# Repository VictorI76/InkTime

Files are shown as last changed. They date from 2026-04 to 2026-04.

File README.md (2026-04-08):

# Proiect Hector Watch - nRF52840 Smartwatch

Acest document conține specificațiile tehnice, Bill of Materials (BOM) și detaliile de design pentru proiectul Hector Watch.

---

# 1. Diagramă Bloc
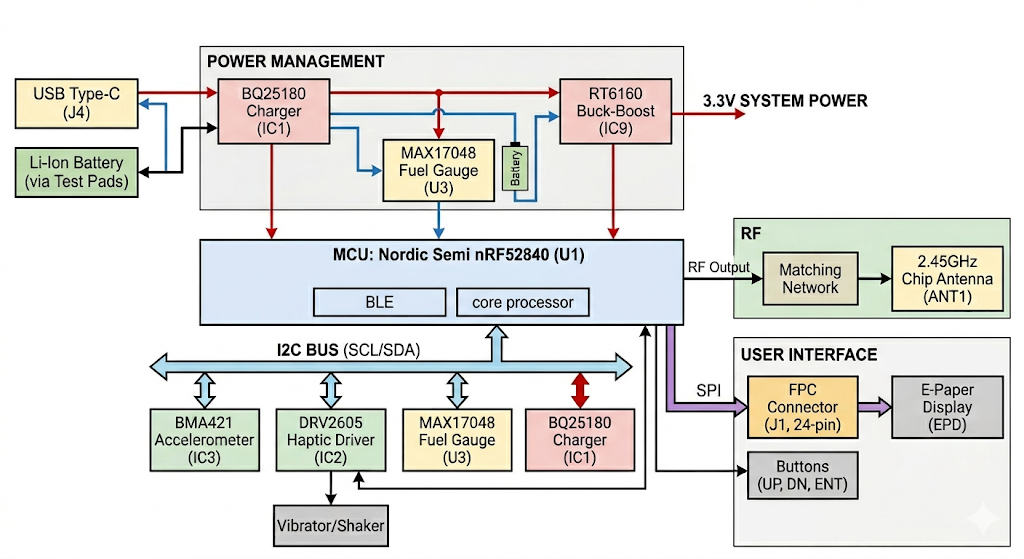
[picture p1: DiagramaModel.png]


---

# 2. Bill Of Materials (BOM)

| Cant. | Referințe | Valoare | Descriere Tehnică | Producător | Cod Piesă (MPN) |
|:---:|:---|:---|:---|:---|:---|
| 1 | U1 | nRF52840 | Microcontroller Bluetooth LE, AQFN-73 | Nordic Semi | nRF52840-QIAA |
| 1 | IC1 | BQ25180 | Charger Li-Ion/Polymer, 8-DSBGA | Texas Instr. | BQ25180YBGR |
| 1 | IC2 | DRV2605 | Driver Haptic LRA/ERM, 9-DSBGA | Texas Instr. | DRV2605YZFR |
| 1 | IC3 | BMA421 | Accelerometru Triaxial 12-bit | Bosch | BMA423 |
| 1 | IC9 | RT6160 | Buck-Boost DC-DC Controller, 15-WL-CSP | Richtek | RT6160AWSC |
| 1 | U3 | MAX17048 | Fuel Gauge (Monitorizare Baterie) | Maxim/ADI | MAX17048G+T10 |
| 1 | ANT1 | 2.45GHz | Antenă Chip Ceramică | Johanson | 2450AT18B100E |
| 1 | J4 | USB-C | Conector USB Type-C 16 pini | Kinghelm | KH-TYPE-C-16P |
| 1 | J1 | FPC 24 | Conector FFC/FPC 0.5mm, 24 pini  | Molex | 503480-2400 |
| 1 | J2 | TC2030 | Interfață programare Tag-Connect | Tag-Connect | TC2030-IDC |
| 3 | SW_DN, SW_ENT, SW_UP | Tactile | Butoane navigare interfață | Panasonic | EVP-AKE31A |
| 1 | L5 | 68uH | Inductor putere ecranat | Wurth | 744043680 |
| 1 | L4 | 0.47uH | Inductor SMD | TDK | FTC252012SR47MBCA |
| 1 | L2 | 10uH | Inductor generic 0402 | - | - |
| 1 | L3 | 15nH | Inductor generic 0201 | - | - |
| 1 | L1 | 3.9nH | Inductor generic 0201  | - | - |
| 1 | X1 | 32MHz | Cristal cuarț (Main Clock)  | - | - |
| 1 | X2 | 32.768kHz | Cristal cuarț (RTC Clock)  | - | - |
| 3 | D2, D4, D5 | MBR0530 | Diodă Schottky 0.5A, 30V, SOD-123 | ON Semi | MBR0530 |
| 1 | D3 | USBLC6-2 | Protecție ESD USB, SOT-23-6 | ST Micro | USBLC6-2SC6Y |
| 1 | Q1 | P-Ch | Tranzistor P-channel MOSFET | - | - |
| 1 | Q3 | N-Ch | Tranzistor N-channel MOSFET 30V, 1.5A | Vishay | Si1308EDL |
| 6 | R2_EP_DR, R5-R9, R_PWR | 10K | Rezistență 0201 Thin Film | - | - |
| 2 | R1_USB, R2_USB | 5K1 | Rezistență 0201 Thin Film  | - | - |
| 2 | R17, R18 | 3K3 | Rezistență 0201 Thin Film  | - | - |
| 3 | R2, R3, R4 | 0 | Rezistență 0201 (Jumper/0 Ohm) | - | - |
| 6 | C5-C19 | 100nF | Condensator decuplare 0201 | - | - |
| 9 | EPD_C1-C12 | 1uF/50V | Condensator 0402 | - | - |
| 5 | C6, C14, C20, C21, C43 | 4.7uF | Condensator 0402  | - | - |
| 3 | C1-EP-DR, C24, C39 | 10uF | Condensator 0402 | - | - |
| 2 | C25, C33 | 22uF | Condensator 0402 | - | - |
| 4 | C23, C27, C34, C42 | 0.1uF | Condensator 0201 | - | - |
| 4 | C1, C2, C17, C18 | 12pF | Condensator 0201 | - | - |
| 14 | TP_3.3V ... TP_VREG | Test Pad | Puncte de testare semnale | - | - |
| 1 | SJ1 | Solder | Jumper de lipit SMD | - | - |

---

# 3. Funcționalității Hardware

## Descrierea Detaliată a Funcționalității Hardware

Proiectul Hector Watch utilizează o arhitectură modulară optimizată pentru eficiență energetică și dimensiuni reduse, având la bază următoarele componente principale:

### 1. Unitatea Centrală de Procesare (MCU)
* **nRF52840 (U1)**: Acesta este un System-on-Chip (SoC) avansat care rulează logica principală a ceasului și gestionează stack-ul Bluetooth Low Energy.
* **Rol**: Controlează comunicația cu toți senzorii prin magistrala **I2C** și interfața digitală pentru display.

### 2. Managementul Puterii (Power Management)
Sistemul de alimentare este proiectat pentru a asigura stabilitate și longevitate bateriei Li-Ion:
* **Încărcător BQ25180 (IC1)**: Gestionează procesul de încărcare a bateriei via USB și include protecții integrate pentru celula de litiu.
* **Regulator Buck-Boost RT6160 (IC9)**: Un convertor DC-DC care stabilizează tensiunea de sistem la 3.3V, indiferent de variațiile tensiunii bateriei.
* **Monitor Baterie MAX17048 (U3)**: Un circuit de tip "Fuel Gauge" care utilizează algoritmul ModelGauge pentru a raporta precis starea de încărcare a bateriei.

## Analiza Consumului de Energie și Autonomie

Pentru a estima durata de viață a bateriei, am analizat principalele stări de funcționare ale componentelor identificate în BOM:

### 1. Consum pe Module (Estimativ)

| Modul / Componentă | Deep Sleep / Standby | Operare Activă (Typical) |
| :--- | :--- | :--- |
| **nRF52840 (U1)** | ~1.5 µA (RTC ON) | ~4.8 mA |
| **BMA421 (IC3)** | ~1 µA (Suspend) | ~14.5 µA (Low Power) |
| **MAX17048 (U3)** | ~3 µA (Hibernate) | ~23 µA (Activ) |
| **RT6160 (IC9)** | ~1 µA (Iq) | Eficiență >85% |
| **Display E-Paper** | **0 µA** (Static) | ~2-8 mA (Refresh doar) |

### 2. Scenariu de Utilizare Tipic
Consumul mediu este calculat pe baza unui ciclu de funcționare (Duty Cycle) în care dispozitivul petrece 99% din timp în mod Sleep:

* **Consum în Sleep (Sistem complet):** ~20 µA (micro-Amperi).
* **Consum în Activitate (Scurte pulsații):** ~5-10 mA (mili-Amperi).
* **Consum Mediu Estimat:** **~55 µA**.

## Calcul Autonomie
Considerând o baterie Li-Ion standard de **200 mAh**:

$$Autonomie (ore) = \frac{Capacitate (mAh)}{Consum Mediu (mA)}$$

$$Autonomie = \frac{200 mAh}{0.055 mA} \approx 3636 \text{ ore}$$

**Rezultat:** Dispozitivul poate funcționa teoretic aproximativ **5 luni** cu o singură încărcare în regim de standby/notificări ocazionale. Utilizarea intensă a motorului haptic (DRV2605) sau refresh-ul frecvent al ecranului va reduce această perioadă la aproximativ **2-4 săptămâni**.

### 3. Senzori și Feedback Haptic
* **Accelerometru BMA421/BMA423 (IC3)**: Senzor de mișcare triaxial cu consum ultra-redus, utilizat pentru pedometru și detecția gesturilor de ridicare a mâinii.
* **Driver Haptic DRV2605 (IC2)**: Controller specializat pentru motoare de vibrație (ERM/LRA) ce oferă o bibliotecă internă de efecte tactile complexe.

### 4. Interfețe și Comunicație
* **Antenă Chip 2.45GHz (ANT1)**: Componentă ceramică acordată pentru frecvența Bluetooth, esențială pentru conexiunea wireless.
* **Conector FPC J1 (24 pini)**: Interfață de 0.5mm utilizată pentru conectarea panoului de afișaj E-Paper.
* **Port USB Type-C (J4)**: Punctul principal de alimentare și încărcare a dispozitivului.
* **Butoane (SW_UP, SW_DN, SW_ENT)**: Trei switch-uri tactice pentru navigarea utilizatorului în meniurile ceasului.

### 5. Protecție și Componente Pasive
* **Protecție ESD USBLC6-2SC6Y (D3)**: Protejează pinii de date USB împotriva descărcărilor electrostatice.
* **Diodă Schottky MBR0530 (D2, D4, D5)**: Componente utilizate pentru redresare și protecția căilor de alimentare.
* **Filtrare locală**: Sistemul utilizează o rețea densă de condensatoare de decuplare (majoritatea în capsulă 0201) pentru a reduce zgomotul electric pe liniile de alimentare.
---

# 4. Alocare Pini nRF52840

## 1. Alimentare și stabilizare

### Pini implicați

* VDD, VDDH
* DEC1, DEC3, DEC4, DEC5, DEC6
* DCC, DCCHP
* VSS (GND)

### Conectare

* VDD este conectat la 3.3V
* VDDH este conectat la sursa principală (baterie sau regulator)
* Pinii DEC sunt conectați la condensatori (100nF, 1µF, 4.7µF) către masă
* DCC și DCCHP sunt conectați la inductoare pentru convertorul DC/DC

### Motivație

* Asigură stabilitatea tensiunilor interne
* Reduce zgomotul electric
* Permite funcționarea eficientă energetic prin utilizarea convertorului DC/DC intern

---

## 2. Interfața RF (2.4 GHz)

### Pini implicați

* ANT
* VSS_PA

### Conectare

* ANT este conectat la o rețea de adaptare (matching network) formată din inductoare și condensatori
* Rețeaua este conectată la antenă

### Motivație

* Adaptarea impedanței la 50 ohmi
* Maximizarea puterii semnalului emis
* Creșterea sensibilității la recepție

---

## 3. Oscilatoare (ceas)

### Pini implicați

* P0.00 (XL1)
* P0.01 (XL2)
* XC1, XC2

### Conectare

* Cristal de 32.768 kHz cu condensatori de 12pF
* Cristal de 32.768 MHz

### Motivație

* Ceasul de 32 kHz este utilizat pentru RTC și moduri low-power
* Ceasul de mare frecvență este necesar pentru comunicații radio precise

---

## 4. Debug și programare (SWD)

### Pini implicați

* SWDIO
* SWDCLK
* RESET
* SWO (opțional)

### Conectare

* Conectați la un header de programare (TC2030)
* Expuse și prin puncte de test

### Motivație

* Programarea firmware-ului
* Debugging în timpul dezvoltării

---

## 5. Interfață USB

### Pini implicați

* D+
* D-
* VBUS

### Conectare

* Conectați la conector USB-C
* Include protecție ESD

### Motivație

* Comunicație USB cu alte dispozitive
* Posibilitate de alimentare prin USB

---

## 6. Interfață SPI – Display E-Paper

### Pini implicați

* MOSI
* SCK
* EPD_CS
* EPD_DC
* EPD_RST
* EPD_BUSY

### Conectare

* Conectați la conectorul display-ului și circuitul de comandă

### Motivație

* SPI oferă comunicație rapidă
* Liniile suplimentare controlează funcționarea display-ului (comenzi, reset, status)

---

## 7. Interfață I2C

### Pini implicați

* SDA
* SCL

### Conectare

* Conectați la:

  * IMU (accelerometru)
  * Fuel gauge
  * Driver haptic
* Include rezistențe de pull-up (~3.3kΩ)

### Motivație

* Permite conectarea mai multor dispozitive pe aceeași magistrală
* Reduce numărul de pini necesari

---

## 8. GPIO și semnale de întrerupere

### Exemple de semnale

* IMU_INT1, IMU_INT2
* PMIC_INT
* HAPTIC_EN
* Butoane

### Conectare

* Intrări/ieșiri digitale configurabile

### Motivație

* Gestionarea evenimentelor asincrone
* Permite funcționare eficientă energetic (bazată pe întreruperi)

---

## 9. Alimentare externă și baterie

### Conectare

* VBUS → USB
* VBAT → baterie LiPo
* Conectate la:

  * Circuit de încărcare
  * Circuit de monitorizare (fuel gauge)

### Motivație

* Management complet al energiei
* Separarea funcțiilor de alimentare și monitorizare

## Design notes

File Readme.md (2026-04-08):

# Proiect Hector Watch - nRF52840 Smartwatch

Acest document conține specificațiile tehnice, Bill of Materials (BOM) și detaliile de design pentru proiectul Hector Watch.

---

# 1. Diagramă Bloc


---

# 2. Bill Of Materials (BOM)

## Bill of Materials (BOM) - Lista Completă de Componente

| Cant. | Referințe | Valoare | Descriere Tehnică | Producător | Cod Piesă (MPN) |
|:---:|:---|:---|:---|:---|:---|
| 1 | U1 | nRF52840 | [cite_start]Microcontroller Bluetooth LE, AQFN-73 [cite: 5] | Nordic Semi | nRF52840-QIAA |
| 1 | IC1 | BQ25180 | [cite_start]Charger Li-Ion/Polymer, 8-DSBGA [cite: 3, 4] | Texas Instr. | BQ25180YBGR |
| 1 | IC2 | DRV2605 | [cite_start]Driver Haptic LRA/ERM, 9-DSBGA [cite: 3, 4] | Texas Instr. | DRV2605YZFR |
| 1 | IC3 | BMA421 | [cite_start]Accelerometru Triaxial 12-bit [cite: 3] | Bosch | BMA423 |
| 1 | IC9 | RT6160 | [cite_start]Buck-Boost DC-DC Controller, 15-WL-CSP [cite: 5] | Richtek | RT6160AWSC |
| 1 | U3 | MAX17048 | [cite_start]Fuel Gauge (Monitorizare Baterie) [cite: 4] | Maxim/ADI | MAX17048G+T10 |
| 1 | ANT1 | 2.45GHz | [cite_start]Antenă Chip Ceramică [cite: 1] | Johanson | 2450AT18B100E |
| 1 | J4 | USB-C | [cite_start]Conector USB Type-C 16 pini [cite: 4] | Kinghelm | KH-TYPE-C-16P |
| 1 | J1 | FPC 24 | [cite_start]Conector FFC/FPC 0.5mm, 24 pini  | Molex | 503480-2400 |
| 1 | J2 | TC2030 | [cite_start]Interfață programare Tag-Connect [cite: 5] | Tag-Connect | TC2030-IDC |
| 3 | SW_DN, SW_ENT, SW_UP | Tactile | [cite_start]Butoane navigare interfață [cite: 1] | Panasonic | EVP-AKE31A |
| 1 | L5 | 68uH | [cite_start]Inductor putere ecranat [cite: 3] | Wurth | 744043680 |
| 1 | L4 | 0.47uH | [cite_start]Inductor SMD [cite: 4] | TDK | FTC252012SR47MBCA |
| 1 | L2 | 10uH | [cite_start]Inductor generic 0402 [cite: 1] | - | - |
| 1 | L3 | 15nH | [cite_start]Inductor generic 0201 [cite: 1] | - | - |
| 1 | L1 | 3.9nH | [cite_start]Inductor generic 0201  | - | - |
| 1 | X1 | 32MHz | [cite_start]Cristal cuarț (Main Clock)  | - | - |
| 1 | X2 | 32.768kHz | [cite_start]Cristal cuarț (RTC Clock)  | - | - |
| 3 | D2, D4, D5 | MBR0530 | [cite_start]Diodă Schottky 0.5A, 30V, SOD-123 [cite: 4] | ON Semi | MBR0530 |
| 1 | D3 | USBLC6-2 | [cite_start]Protecție ESD USB, SOT-23-6 [cite: 4] | ST Micro | USBLC6-2SC6Y |
| 1 | Q1 | P-Ch | [cite_start]Tranzistor P-channel MOSFET [cite: 4] | - | - |
| 1 | Q3 | N-Ch | [cite_start]Tranzistor N-channel MOSFET 30V, 1.5A [cite: 4] | Vishay | Si1308EDL |
| 6 | R2_EP_DR, R5-R9, R_PWR | 10K | [cite_start]Rezistență 0201 Thin Film [cite: 1] | - | - |
| 2 | R1_USB, R2_USB | 5K1 | [cite_start]Rezistență 0201 Thin Film  | - | - |
| 2 | R17, R18 | 3K3 | [cite_start]Rezistență 0201 Thin Film  | - | - |
| 3 | R2, R3, R4 | 0 | [cite_start]Rezistență 0201 (Jumper/0 Ohm) [cite: 1] | - | - |
| 6 | C5-C19 | 100nF | [cite_start]Condensator decuplare 0201 [cite: 1] | - | - |
| 9 | EPD_C1-C12 | 1uF/50V | [cite_start]Condensator 0402 [cite: 1] | - | - |
| 5 | C6, C14, C20, C21, C43 | 4.7uF | [cite_start]Condensator 0402  | - | - |
| 3 | C1-EP-DR, C24, C39 | 10uF | [cite_start]Condensator 0402 [cite: 1] | - | - |
| 2 | C25, C33 | 22uF | [cite_start]Condensator 0402 [cite: 1] | - | - |
| 4 | C23, C27, C34, C42 | 0.1uF | [cite_start]Condensator 0201 [cite: 1] | - | - |
| 4 | C1, C2, C17, C18 | 12pF | [cite_start]Condensator 0201 [cite: 1] | - | - |
| 14 | TP_3.3V ... TP_VREG | Test Pad | [cite_start]Puncte de testare semnale [cite: 4] | - | - |
| 1 | SJ1 | Solder | [cite_start]Jumper de lipit SMD [cite: 1] | - | - |

---

# 3. Funcționalitate Hardware
### Module și Interfețe
## Descrierea Detaliată a Funcționalității Hardware

Descrierea Detaliată a Funcționalității Hardware

Proiectul Hector Watch utilizează o arhitectură modulară optimizată pentru eficiență energetică și dimensiuni reduse, având la bază următoarele componente principale:

### 1. Unitatea Centrală de Procesare (MCU)
* **nRF52840 (U1)**: Acesta este un System-on-Chip (SoC) avansat care rulează logica principală a ceasului și gestionează stack-ul Bluetooth Low Energy.
* **Rol**: Controlează comunicația cu toți senzorii prin magistrala **I2C** și interfața digitală pentru display.

### 2. Managementul Puterii (Power Management)
Sistemul de alimentare este proiectat pentru a asigura stabilitate și longevitate bateriei Li-Ion:
* **Încărcător BQ25180 (IC1)**: Gestionează procesul de încărcare a bateriei via USB și include protecții integrate pentru celula de litiu.
* **Regulator Buck-Boost RT6160 (IC9)**: Un convertor DC-DC care stabilizează tensiunea de sistem la 3.3V, indiferent de variațiile tensiunii bateriei.
* **Monitor Baterie MAX17048 (U3)**: Un circuit de tip "Fuel Gauge" care utilizează algoritmul ModelGauge pentru a raporta precis starea de încărcare a bateriei.

## Analiza Consumului de Energie și Autonomie

[cite_start]Pentru a estima durata de viață a bateriei, am analizat principalele stări de funcționare ale componentelor identificate în BOM[cite: 1]:

### 1. Consum pe Module (Estimativ)

| Modul / Componentă | Deep Sleep / Standby | Operare Activă (Typical) |
| :--- | :--- | :--- |
| **nRF52840 (U1)** | ~1.5 µA (RTC ON) | ~4.8 mA (TX @ 0dBm) |
| **BMA421 (IC3)** | ~1 µA (Suspend) | ~14.5 µA (Low Power) |
| **MAX17048 (U3)** | ~3 µA (Hibernate) | ~23 µA (Activ) |
| **RT6160 (IC9)** | ~1 µA (Iq) | Eficiență >85% |
| **Display E-Paper** | **0 µA** (Static) | ~2-8 mA (Refresh doar) |

### 2. Scenariu de Utilizare Tipic
Consumul mediu este calculat pe baza unui ciclu de funcționare (Duty Cycle) în care dispozitivul petrece 99% din timp în mod Sleep:

* [cite_start]**Consum în Sleep (Sistem complet):** ~20 µA (micro-Amperi).
* [cite_start]**Consum în Activitate (Scurte pulsații):** ~5-10 mA (mili-Amperi).
* **Consum Mediu Estimat:** **~55 µA**.

## Calcul Autonomie
Considerând o baterie Li-Ion standard de **200 mAh**:

$$Autonomie (ore) = \frac{Capacitate (mAh)}{Consum Mediu (mA)}$$

$$Autonomie = \frac{200 mAh}{0.055 mA} \approx 3636 \text{ ore}$$

**Rezultat:** Dispozitivul poate funcționa teoretic aproximativ **5 luni** cu o singură încărcare în regim de standby/notificări ocazionale. Utilizarea intensă a motorului haptic (DRV2605) sau refresh-ul frecvent al ecranului va reduce această perioadă la aproximativ **2-4 săptămâni**.

### 3. Senzori și Feedback Haptic
* **Accelerometru BMA421/BMA423 (IC3)**: Senzor de mișcare triaxial cu consum ultra-redus, utilizat pentru pedometru și detecția gesturilor de ridicare a mâinii.
* **Driver Haptic DRV2605 (IC2)**: Controller specializat pentru motoare de vibrație (ERM/LRA) ce oferă o bibliotecă internă de efecte tactile complexe.

### 4. Interfețe și Comunicație
* **Antenă Chip 2.45GHz (ANT1)**: Componentă ceramică acordată pentru frecvența Bluetooth, esențială pentru conexiunea wireless.
* **Conector FPC J1 (24 pini)**: Interfață de 0.5mm utilizată pentru conectarea panoului de afișaj E-Paper.
* **Port USB Type-C (J4)**: Punctul principal de alimentare și încărcare a dispozitivului.
* **Butoane (SW_UP, SW_DN, SW_ENT)**: Trei switch-uri tactice pentru navigarea utilizatorului în meniurile ceasului.

### 5. Protecție și Componente Pasive
* **Protecție ESD USBLC6-2SC6Y (D3)**: Protejează pinii de date USB împotriva descărcărilor electrostatice.
* [cite_start]**Diodă Schottky MBR0530 (D2, D4, D5)**: Componente utilizate pentru redresare și protecția căilor de alimentare.
* [cite_start]**Filtrare locală**: Sistemul utilizează o rețea densă de condensatoare de decuplare (majoritatea în capsulă 0201) pentru a reduce zgomotul electric pe liniile de alimentare.
---

# 4. Alocare Pini nRF52840
# nRF52840 – Conectarea pinilor

## 1. Alimentare și stabilizare

### Pini implicați

* VDD, VDDH
* DEC1, DEC3, DEC4, DEC5, DEC6
* DCC, DCCHP
* VSS (GND)

### Conectare

* VDD este conectat la 3.3V
* VDDH este conectat la sursa principală (baterie sau regulator)
* Pinii DEC sunt conectați la condensatori (100nF, 1µF, 4.7µF) către masă
* DCC și DCCHP sunt conectați la inductoare pentru convertorul DC/DC

### Motivație

* Asigură stabilitatea tensiunilor interne
* Reduce zgomotul electric
* Permite funcționarea eficientă energetic prin utilizarea convertorului DC/DC intern

---

## 2. Interfața RF (2.4 GHz)

### Pini implicați

* ANT
* VSS_PA

### Conectare

* ANT este conectat la o rețea de adaptare (matching network) formată din inductoare și condensatori
* Rețeaua este conectată la antenă

### Motivație

* Adaptarea impedanței la 50 ohmi
* Maximizarea puterii semnalului emis
* Creșterea sensibilității la recepție

---

## 3. Oscilatoare (ceas)

### Pini implicați

* P0.00 (XL1)
* P0.01 (XL2)
* XC1, XC2

### Conectare

* Cristal de 32.768 kHz cu condensatori de 12pF
* Cristal de 32.768 MHz

### Motivație

* Ceasul de 32 kHz este utilizat pentru RTC și moduri low-power
* Ceasul de mare frecvență este necesar pentru comunicații radio precise

---

## 4. Debug și programare (SWD)

### Pini implicați

* SWDIO
* SWDCLK
* RESET
* SWO (opțional)

### Conectare

* Conectați la un header de programare (TC2030)
* Expuse și prin puncte de test

### Motivație

* Programarea firmware-ului
* Debugging în timpul dezvoltării

---

## 5. Interfață USB

### Pini implicați

* D+
* D-
* VBUS

### Conectare

* Conectați la conector USB-C
* Include protecție ESD

### Motivație

* Comunicație USB cu alte dispozitive
* Posibilitate de alimentare prin USB

---

## 6. Interfață SPI – Display E-Paper

### Pini implicați

* MOSI
* SCK
* EPD_CS
* EPD_DC
* EPD_RST
* EPD_BUSY

### Conectare

* Conectați la conectorul display-ului și circuitul de comandă

### Motivație

* SPI oferă comunicație rapidă
* Liniile suplimentare controlează funcționarea display-ului (comenzi, reset, status)

---

## 7. Interfață I2C

### Pini implicați

* SDA
* SCL

### Conectare

* Conectați la:

  * IMU (accelerometru)
  * Fuel gauge
  * Driver haptic
* Include rezistențe de pull-up (~3.3kΩ)

### Motivație

* Permite conectarea mai multor dispozitive pe aceeași magistrală
* Reduce numărul de pini necesari

---

## 8. GPIO și semnale de întrerupere

### Exemple de semnale

* IMU_INT1, IMU_INT2
* PMIC_INT
* HAPTIC_EN
* Butoane

### Conectare

* Intrări/ieșiri digitale configurabile

### Motivație

* Gestionarea evenimentelor asincrone
* Permite funcționare eficientă energetic (bazată pe întreruperi)

---

## 9. Alimentare externă și baterie

### Conectare

* VBUS → USB
* VBAT → baterie LiPo
* Conectate la:

  * Circuit de încărcare
  * Circuit de monitorizare (fuel gauge)

### Motivație

* Management complet al energiei
* Separarea funcțiilor de alimentare și monitorizare

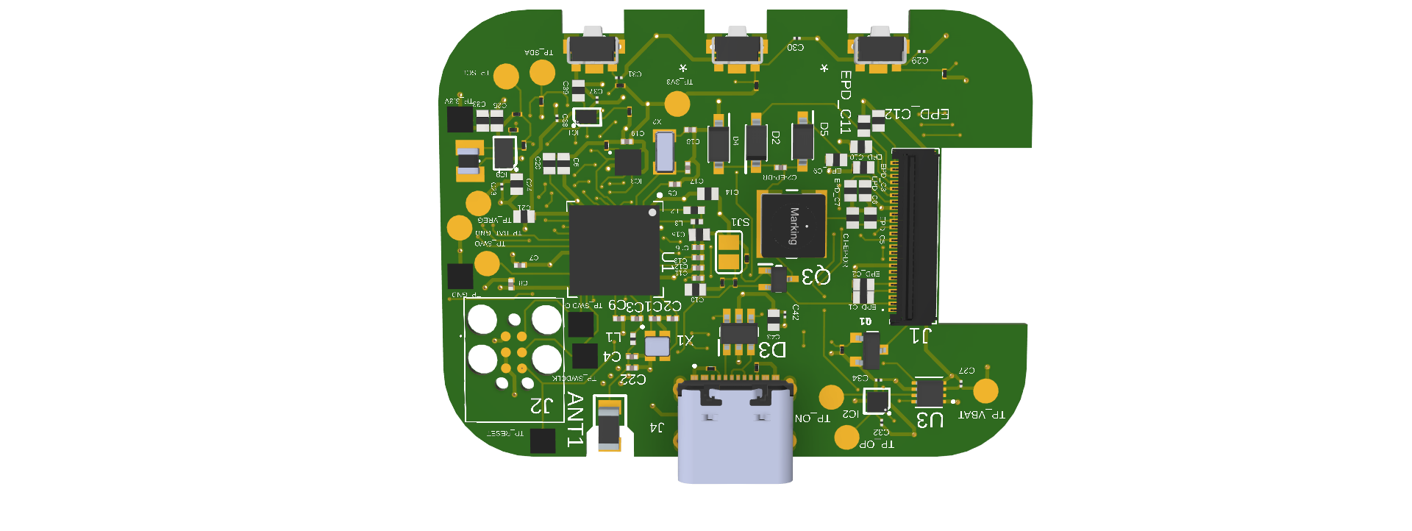
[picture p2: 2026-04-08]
Images/InkTime_PCB_Top.png

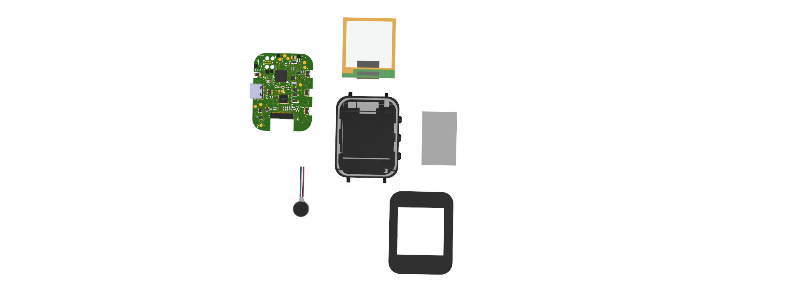
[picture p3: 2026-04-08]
Images/FullWatch_Exploded.png

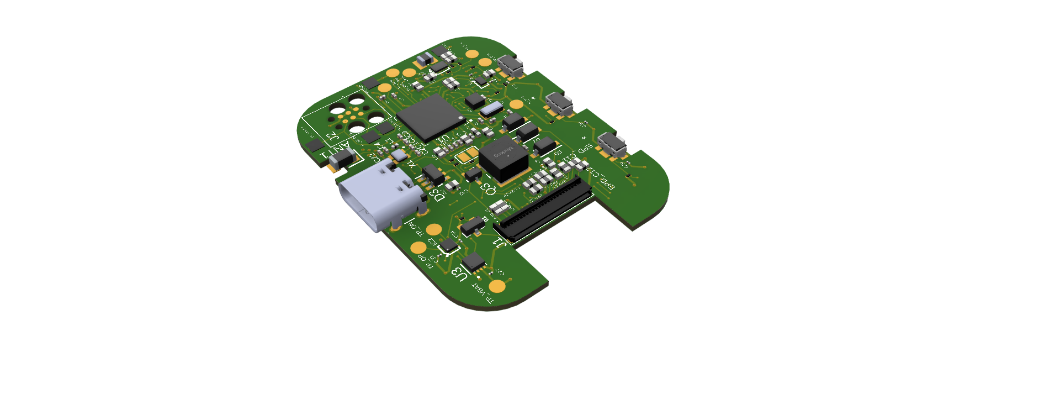
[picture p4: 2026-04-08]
Images/InkTime_PCB_3.png

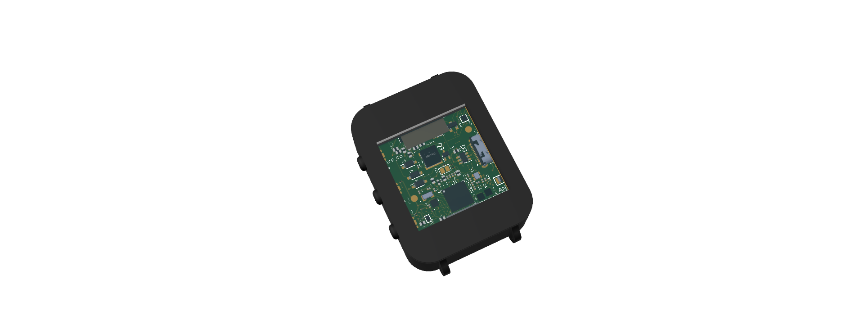
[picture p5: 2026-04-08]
Images/FullWatch_1.png

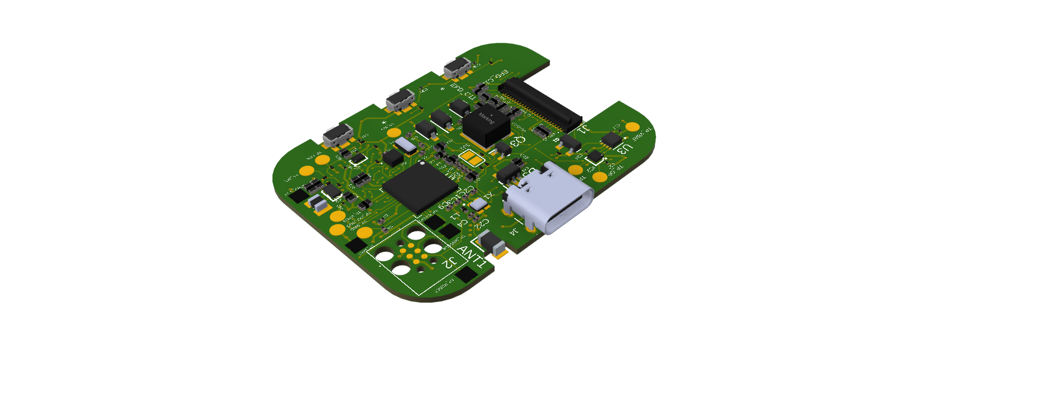
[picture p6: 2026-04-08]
Images/InkTime_PCB_4.png

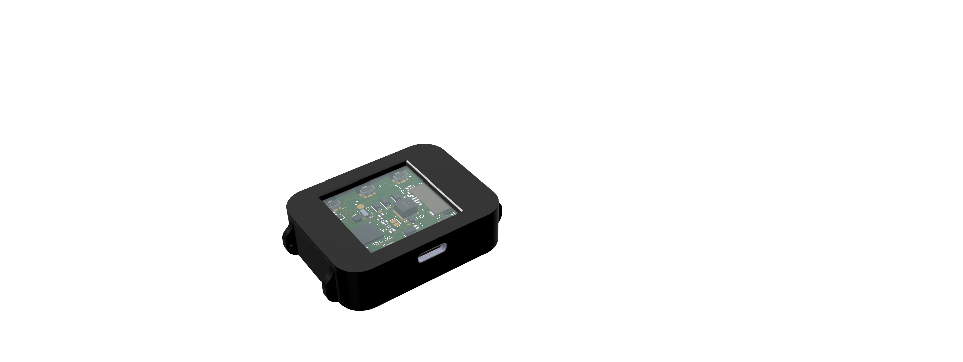
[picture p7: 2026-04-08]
Images/FullWatch_2.png

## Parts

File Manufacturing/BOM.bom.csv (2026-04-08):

Qty | Value | Device | Package | Parts | Description | ARROW_PART_NUMBER | ARROW_PRICE-STOCK | COPYRIGHT | DESCRIPTION | HEIGHT | JLCPCB | MANUFACTURER_NAME | MANUFACTURER_PART_NUMBER | MFR_NAME | MOUSER_PART_NUMBER | MOUSER_PRICE-STOCK | PACKAGE | POPULARITY | PROD_ID | TP_SIGNAL_NAME
1 |  | ESP32_C6_LIBRARY_7_JUMPER_SJ | ESP32_C6_LIBRARY_7_JUMPER_SJ | SJ1 | SMD solder JUMPER |  |  |  |  |  |  |  |  |  |  |  |  | 3
3 | 0 | CPF0201D7K68C1_CPF0201D7K68C1 | CPF0201D7K68C1_0201 | R2, R3, R4 | 7.68k 0201 Thin Film Surface Mount Fixed Resistor +/-0.5% 0.031W CPF0201D7K68C1
4 | 0.1uF | GRM011R60J152KE01L_2_GRM011R60J152KE01LGRM011R60J152KE01L | GRM011R60J152KE01L_2_CAPC0201X13N | C23, C27, C34, C42 | Check availability
1 | 0.1uF/50V | NORDIC_NRF_3_CAPACITORCAPACITOR_4020 | NORDIC_NRF_3_RESC0402_N | EPD_C5 | Generic chip capacitor
2 | 0.47 | CPF0201D7K68C1_CPF0201D7K68C1 | CPF0201D7K68C1_0201 | R1_EP_DR, R1_TYPE_SEL | 7.68k 0201 Thin Film Surface Mount Fixed Resistor +/-0.5% 0.031W CPF0201D7K68C1
1 | 1.0uF | NORDIC_NRF_3_CAPACITORCAPACITOR_4020 | NORDIC_NRF_3_RESC0402_N | C15 | Generic chip capacitor
6 | 100nF | NORDIC_NRF_3_CAPACITOR_0201_N | NORDIC_NRF_3_RESC0201_N | C5, C7, C8, C12, C16, C19 | Generic chip capacitor
1 | 100pF | NORDIC_NRF_3_CAPACITOR_0201_N | NORDIC_NRF_3_RESC0201_N | C11 | Generic chip capacitor
6 | 10K | CPF0201D7K68C1_CPF0201D7K68C1 | CPF0201D7K68C1_0201 | R2_EP_DR, R5, R7, R8, R9, R_PWR_EPD | 7.68k 0201 Thin Film Surface Mount Fixed Resistor +/-0.5% 0.031W CPF0201D7K68C1
3 | 10uF | NORDIC_NRF_3_CAPACITORCAPACITOR_4020 | NORDIC_NRF_3_RESC0402_N | C1-EP-DR, C24, C39 | Generic chip capacitor
1 | 10uH | NORDIC_NRF_2_INDUCTOR_0402_N | NORDIC_NRF_2_RESC0402_N | L2 | Generic chip inductor
4 | 12pF | NORDIC_NRF_3_CAPACITOR_0201_N | NORDIC_NRF_3_RESC0201_N | C1, C2, C17, C18 | Generic chip capacitor
1 | 15nH | NORDIC_NRF_2_INDUCTOR_0201_N | NORDIC_NRF_2_RESC0201_N | L3 | Generic chip inductor
2 | 1pF | NORDIC_NRF_3_CAPACITOR_0201_N | NORDIC_NRF_3_RESC0201_N | C3, C4 | Generic chip capacitor
6 | 1uF | GRM011R60J152KE01L_2_GRM011R60J152KE01LGRM011R60J152KE01L | GRM011R60J152KE01L_2_CAPC0201X13N | C29, C30, C31, C32, C37, C38 | Check availability
9 | 1uF/50V | NORDIC_NRF_3_CAPACITORCAPACITOR_4020 | NORDIC_NRF_3_RESC0402_N | EPD_C1, EPD_C2, EPD_C6, EPD_C7, EPD_C8, EPD_C9, EPD_C10, EPD_C11, EPD_C12 | Generic chip capacitor
3 | 2025-10-22_07-23-44_LIBRARY_EVP-AKE31A | 2025-10-22_07-23-44_LIBRARY_EVP-AKE31A | 2025-10-22_07-23-44_LIBRARY_SW_EVP-AKE31A_PAN | SW_DN, SW_ENT, SW_UP
2 | 22uF | NORDIC_NRF_3_CAPACITORCAPACITOR_4020 | NORDIC_NRF_3_RESC0402_N | C25, C33 | Generic chip capacitor
1 | 2450AT18B100E_2450AT18B100E | 2450AT18B100E_2450AT18B100E | 2450AT18B100E_ANTC3216X140N | ANT1 | Antennas 2.45GHz ANTENNA | 2450AT18B100E | https://www.arrow.com/en/products/2450at18b100e/johanson-dielectrics?utm_currency=USD&region=nac |  | Antennas 2.45GHz ANTENNA | 1.4mm |  | JOHANSON TECHNOLOGY | 2450AT18B100E |  | 609-2450AT18B100E | https://www.mouser.co.uk/ProductDetail/Johanson-Technology/2450AT18B100E?qs=yCnrNFeXz%252Bh5MFsFIXGZGA%3D%3D
1 | 3.9nH | NORDIC_NRF_2_INDUCTOR_0201_N | NORDIC_NRF_2_RESC0201_N | L1 | Generic chip inductor
1 | 32.768kHz | NORDIC_NRF_1_XTAL_32KHZ | NORDIC_NRF_1_XTAL_3215_N | X2
1 | 32MHz | NORDIC_NRF_XTAL_32MHZ | NORDIC_NRF_BT-XTAL_2016_N | X1
2 | 3K3 | CPF0201D7K68C1_CPF0201D7K68C1 | CPF0201D7K68C1_0201 | R17, R18 | 7.68k 0201 Thin Film Surface Mount Fixed Resistor +/-0.5% 0.031W CPF0201D7K68C1
5 | 4.7uF | NORDIC_NRF_3_CAPACITORCAPACITOR_4020 | NORDIC_NRF_3_RESC0402_N | C6, C14, C20, C21, C43 | Generic chip capacitor
1 | 4.7uF/25V | NORDIC_NRF_3_CAPACITOR_0201_N | NORDIC_NRF_3_RESC0201_N | C2-EP-DR | Generic chip capacitor
1 | 503480-2400_503480-2400 | 503480-2400_503480-2400 | 503480-2400_5034802400 | J1 | FFC & FPC Connectors 0.5mm FPC RA SMT Dual Contact 24Ckt |  |  |  | FFC & FPC Connectors 0.5mm FPC RA SMT Dual Contact 24Ckt | 1.87mm |  | Molex | 503480-2400 |  | 538-503480-2400 | https://www.mouser.co.uk/ProductDetail/Molex/503480-2400?qs=OAhjpuo3Vu7efIoxFh9AOw%3D%3D
2 | 5K1 | CPF0201D7K68C1_CPF0201D7K68C1 | CPF0201D7K68C1_0201 | R1_USB, R2_USB | 7.68k 0201 Thin Film Surface Mount Fixed Resistor +/-0.5% 0.031W CPF0201D7K68C1
1 | 68uH | ESP32_C6_LIBRARY_2_744043680IND_4828-WE-TPC_WRE | ESP32_C6_LIBRARY_2_IND_4828-WE-TPC_WRE | L5 |  |  |  | Copyright (C) 2024 Ultra Librarian. All rights reserved. |  |  |  |  | 744043680 | Wurth Electronics
1 | 820pF N.C. | NORDIC_NRF_3_CAPACITOR_0201_N | NORDIC_NRF_3_RESC0201_N | C9 | Generic chip capacitor
1 | BMA421 | BMA423_BMA423 | BMA423_BMA423 | IC3 | Accelerometers Triaxial low-g 12bit Acceleration Sensor | BMA423 | https://www.arrow.com/en/products/bma423/bosch |  | Accelerometers Triaxial low-g 12bit Acceleration Sensor | 1mm |  | BOSCH | BMA423 |  | 262-BMA423 | https://www.mouser.co.uk/ProductDetail/Bosch-Sensortec/BMA423?qs=HXFqYaX1Q2xC%252BSgeGoX3mg%3D%3D
1 | BQ25180YBGR_BQ25180YBGR | BQ25180YBGR_BQ25180YBGR | BQ25180YBGR_BGA8C40P2X4_100X155X50 | IC1 | Charger IC Lithium Ion/Polymer, Lithium Iron Phosphate 8-DSBGA (1.6x1.1) | BQ25180YBGR | https://www.arrow.com/en/products/bq25180ybgr/texas-instruments?utm_currency=USD&region=nac |  | Charger IC Lithium Ion/Polymer | Lithium Iron Phosphate 8-DSBGA (1.6x1.1) | 0.5mm |  | Texas Instruments | BQ25180YBGR |  | 595-BQ25180YBGR | https://www.mouser.co.uk/ProductDetail/Texas-Instruments/BQ25180YBGR?qs=doiCPypUmgEWjAK%252BJAX6Tw%3D%3D
1 | DRV2605YZFR_DRV2605YZFR | DRV2605YZFR_DRV2605YZFR | DRV2605YZFR_BGA9C50P3X3_144X144X62 | IC2 | Haptic Driver for ERM/LRA with Built-In Library and Smart Loop Architecture | DRV2605YZFR | https://www.arrow.com/en/products/drv2605yzfr/texas-instruments?region=nac |  | Haptic Driver for ERM/LRA with Built-In Library and Smart Loop Architecture | 0.625mm |  | Texas Instruments | DRV2605YZFR
1 | ESP32_C6_LIBRARY_3_USBLC6-2SC6YUSBLC6-2SC6Y | ESP32_C6_LIBRARY_3_USBLC6-2SC6YUSBLC6-2SC6Y | ESP32_C6_LIBRARY_3_SOT95P280X145-6N | D3 | Low Cap. ESD Protection Auto SOT-23-6 STMicroelectronics USBLC6-2SC6Y, Dual Uni-Directional TVS Diode Array, 6-Pin SOT-23
1 | ESP32_C6_LIBRARY_4_ESP32_WROVER_SPARKFUN-DISCRETESEMI_MOSFET_PCH | ESP32_C6_LIBRARY_4_ESP32_WROVER_SPARKFUN-DISCRETESEMI_MOSFET_PCH | ESP32_C6_LIBRARY_4_ESP32_C6_LIBRARY_4_ESP32_C6_LIBRARY_4_ESP32_C6_LIBRARY_4_ESP32_WROVER_SPARKFUN-DISCRETESEMI_SOT23-3 | Q1 | P-channel MOSFETs
3 | ESP32_C6_LIBRARY_5_MBR0530MBR0530T | ESP32_C6_LIBRARY_5_MBR0530MBR0530T | ESP32_C6_LIBRARY_5_SOD3716X135N | D2, D4, D5 | ON SEMICONDUCTOR - MBR0530 - DIODE, SCHOTTKY, 0.5A, 30V, SOD-123
1 | ESP32_C6_LIBRARY_6_SI1308EDL-T1-GE3SI1308EDL-T1-GE3 | ESP32_C6_LIBRARY_6_SI1308EDL-T1-GE3SI1308EDL-T1-GE3 | ESP32_C6_LIBRARY_6_SOT65P210X110-3N | Q3 | MOSFET N-Ch 30V 1.5A TrenchFET SC70 Vishay Si1308EDL-T1-GE3 N-channel MOSFET Transistor, 1.5 A, 30 V, 3-Pin SC-70
1 | ESP32_C6_LIBRARY_MAX17048G+T10MAX17048G+T10 | ESP32_C6_LIBRARY_MAX17048G+T10MAX17048G+T10 | ESP32_C6_LIBRARY_SON50P200X200X80-9N | U3 | Check availability
14 | HECTOR_WATCH_1_TPTP20R | HECTOR_WATCH_1_TPTP20R | HECTOR_WATCH_1_TP20R | TP_3.3V, TP_3V3, TP_BAT_GND, TP_GND, TP_ON, TP_OP, TP_RESET, TP_SCL, TP_SDA, TP_SWDCLK, TP_SWDIO, TP_SWO, TP_VBAT, TP_VREG | Test pad |  |  |  |  |  |  |  |  |  |  |  |  | 2
1 | KH-TYPE-C-16P_KH-TYPE-C-16PKH-TYPE-C-16P_VICTOR | KH-TYPE-C-16P_KH-TYPE-C-16PKH-TYPE-C-16P_VICTOR | KH-TYPE-C-16P_KINGHELM_KH-TYPE-C-16P | J4 | Check availability
1 | MLP2016SR47MT0S1_FTC252012SR47MBCA | MLP2016SR47MT0S1_FTC252012SR47MBCA | MLP2016SR47MT0S1_INDC2016X100N | L4 | SMD / SMT Inductors (Coils), L=0.47?H, L x W x T : |  |  |  | SMD / SMT Inductors (Coils) | L=0.47?H | L x W x T : | 1mm | https://jlcpcb.com/partdetail/6763488-FTC252012SR47MBCA/C5832368 | TDK | FTC252012SR47MBCA
1 | N.C. | NORDIC_NRF_3_CAPACITORCAPACITOR_4020 | NORDIC_NRF_3_RESC0402_N | C10 | Generic chip capacitor
2 | N.C. | NORDIC_NRF_3_CAPACITOR_0201_N | NORDIC_NRF_3_RESC0201_N | C13, C22 | Generic chip capacitor
1 | NORDIC_NRF_4_NRF52840_QF | NORDIC_NRF_4_NRF52840_QF | NORDIC_NRF_4_AQFN50P700X700X85_HS-74N | U1 | nRF52840
1 | RT6160AWSC_RT6160AWSC | RT6160AWSC_RT6160AWSC | RT6160AWSC_BGA15C40P3X5_140X230X60 | IC9 | Buck-Boost Regulator Positive Output Step-Up/Step-Down I2C DC-DC Controller IC 15-WL-CSP (BSC) (1.4x2.3) |  |  |  | Buck-Boost Regulator Positive Output Step-Up/Step-Down I2C DC-DC Controller IC 15-WL-CSP (BSC) (1.4x2.3) | 0.6mm |  | RICHTEK | RT6160AWSC |  | 835-RT6160AWSC | https://www.mouser.co.uk/ProductDetail/Richtek/RT6160AWSC?qs=amGC7iS6iy%2FLd9PSoixZXQ%3D%3D
1 | TC2030-IDC_TC2030-IDC | TC2030-IDC_TC2030-IDC | TC2030-IDC_TC2030IDC | J2 | CABLE ADAPTER 6 POS |  |  |  | CABLE ADAPTER 6 POS | 19mm |  | Tag Connect | TC2030-IDC

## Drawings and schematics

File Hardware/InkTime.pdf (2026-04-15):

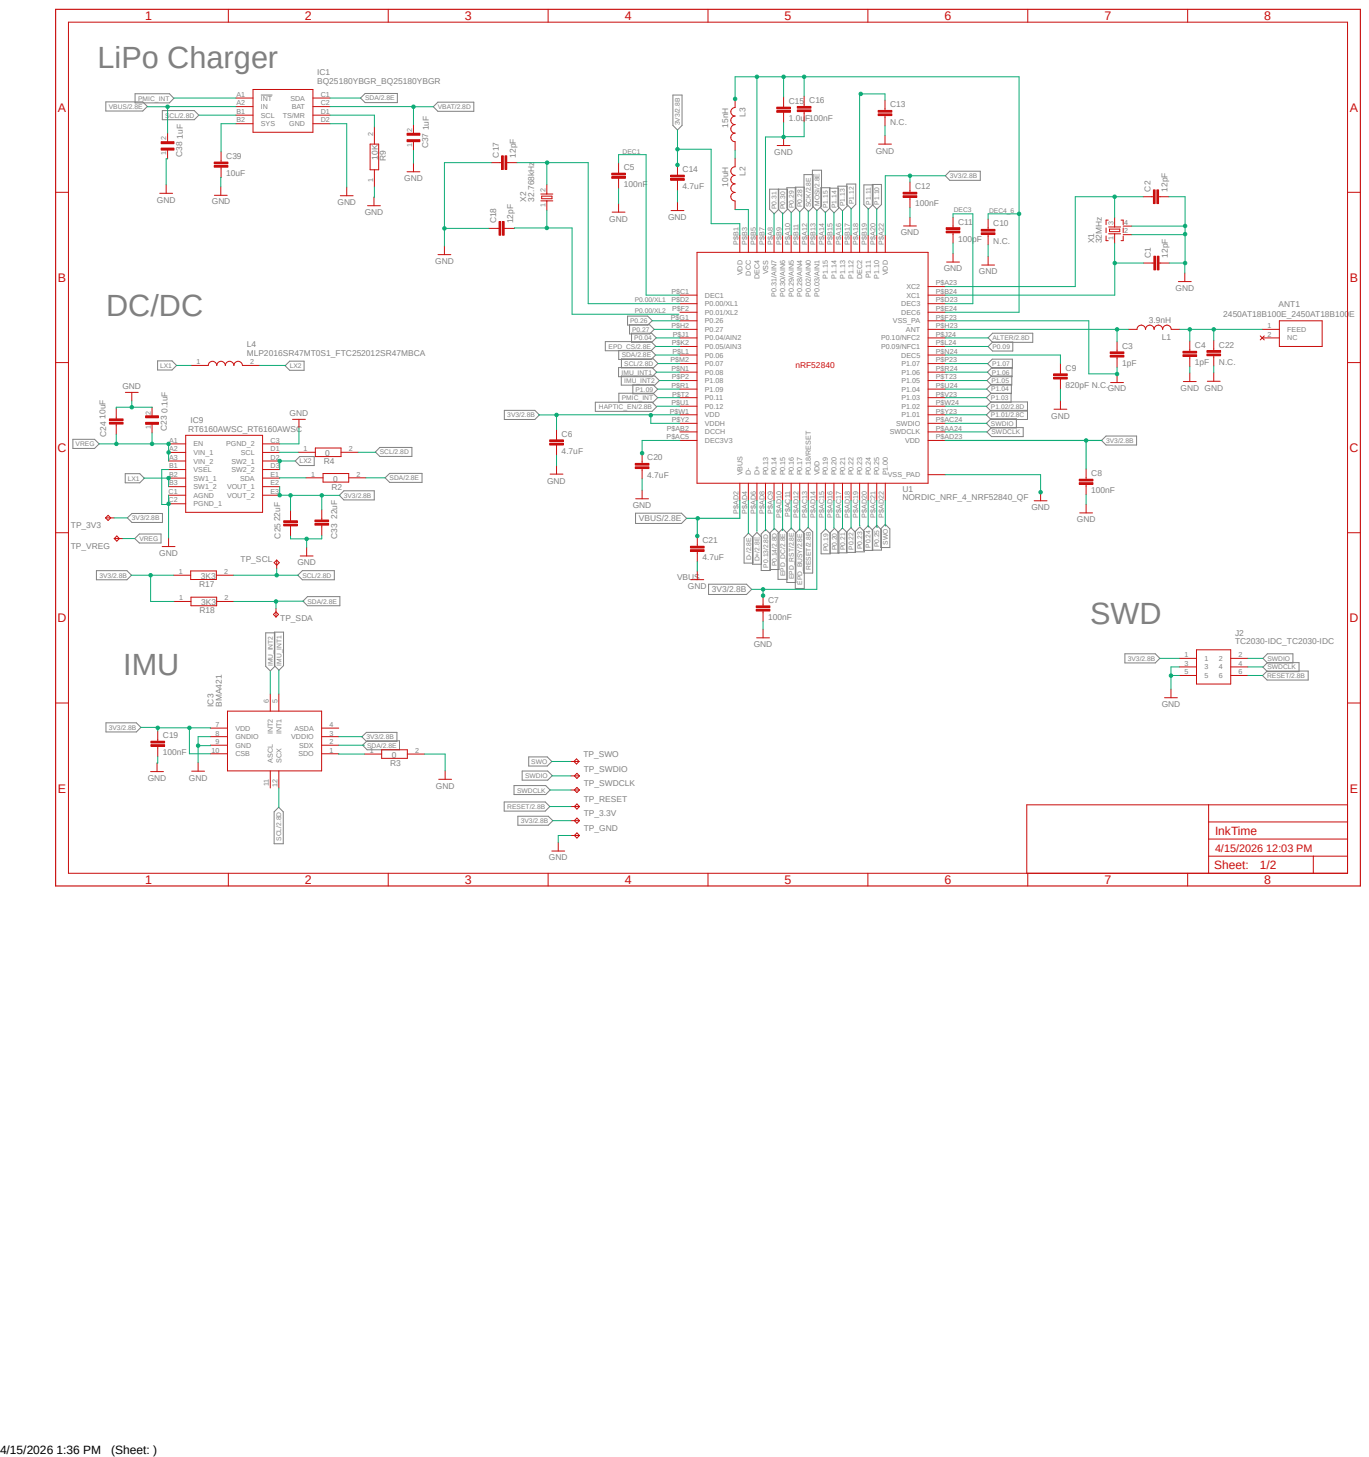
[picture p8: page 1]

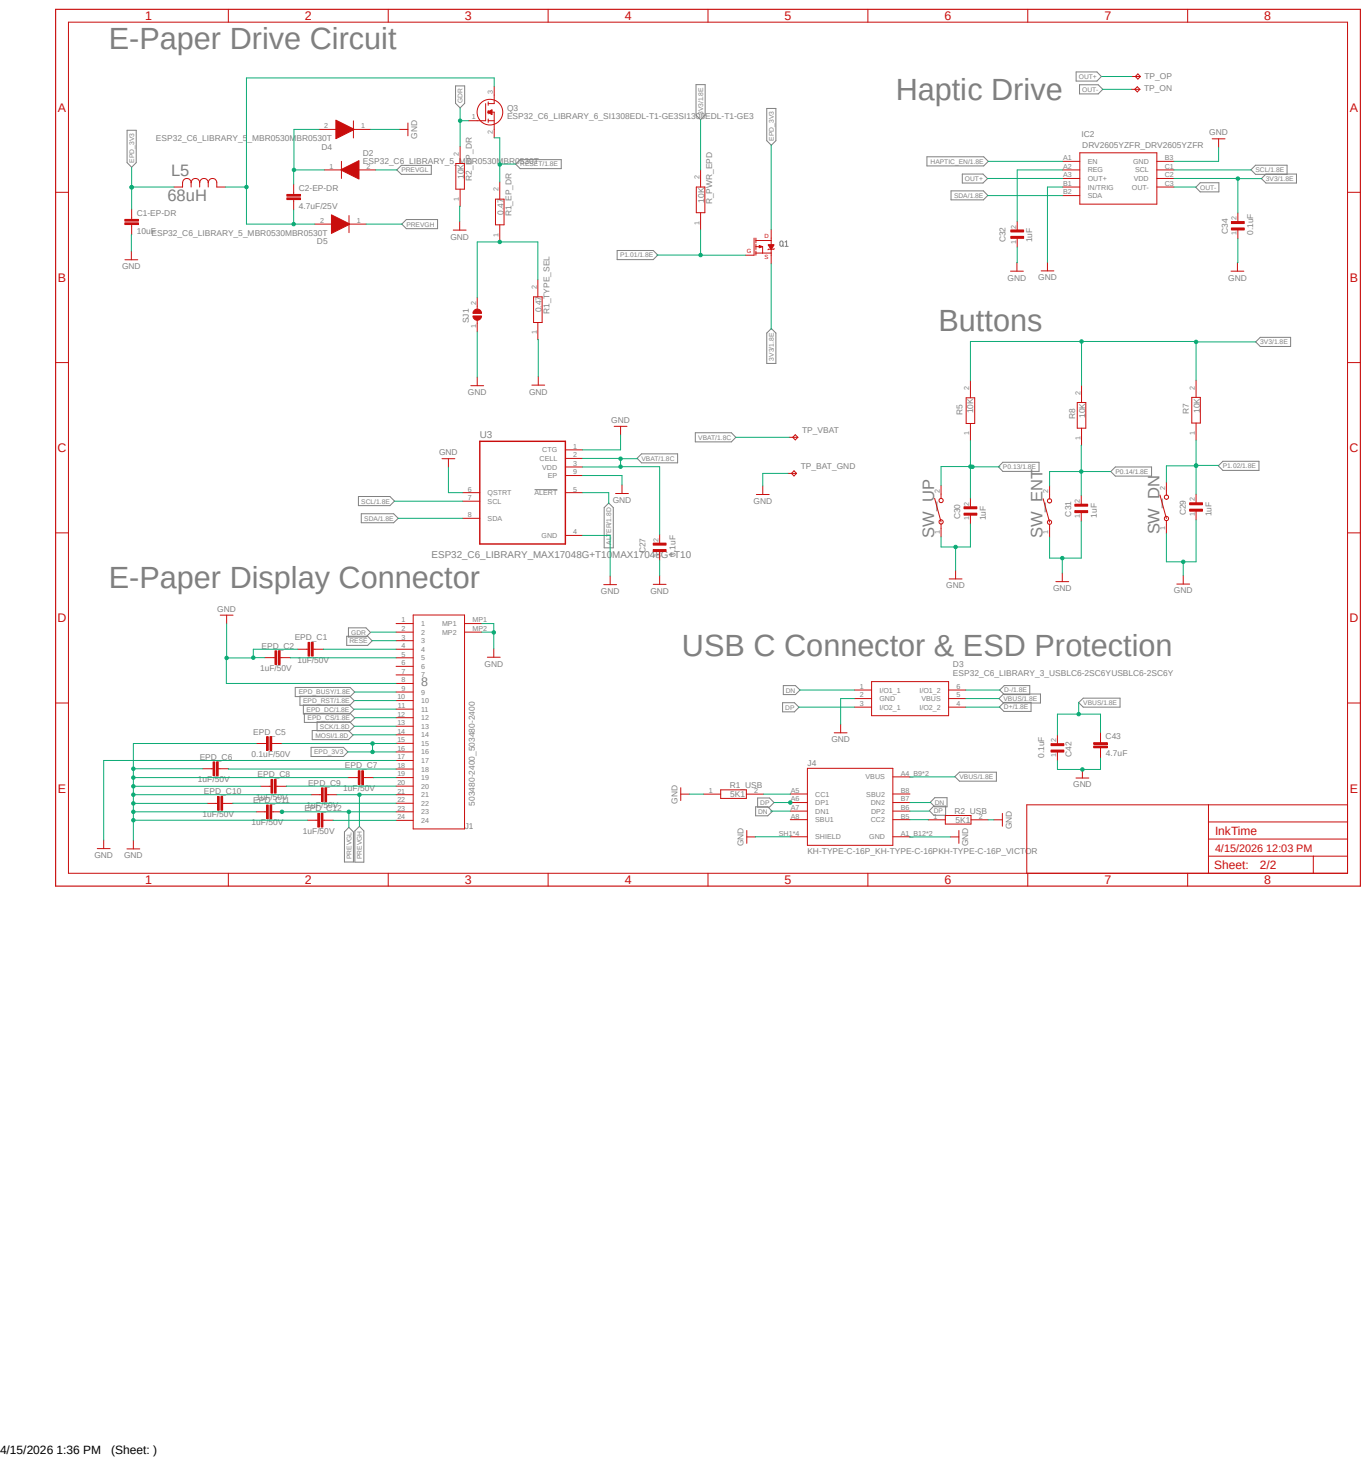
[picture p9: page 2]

USB C Connector & ESD Protection

EPD_C10 | | 1uF/50V | 21 21

1uF/50V EPD_C11 | | | 22 22

KH-TYPE-C-16P_KH-TYPE-C-16PKH-TYPE-C-16P_VICTOR GND

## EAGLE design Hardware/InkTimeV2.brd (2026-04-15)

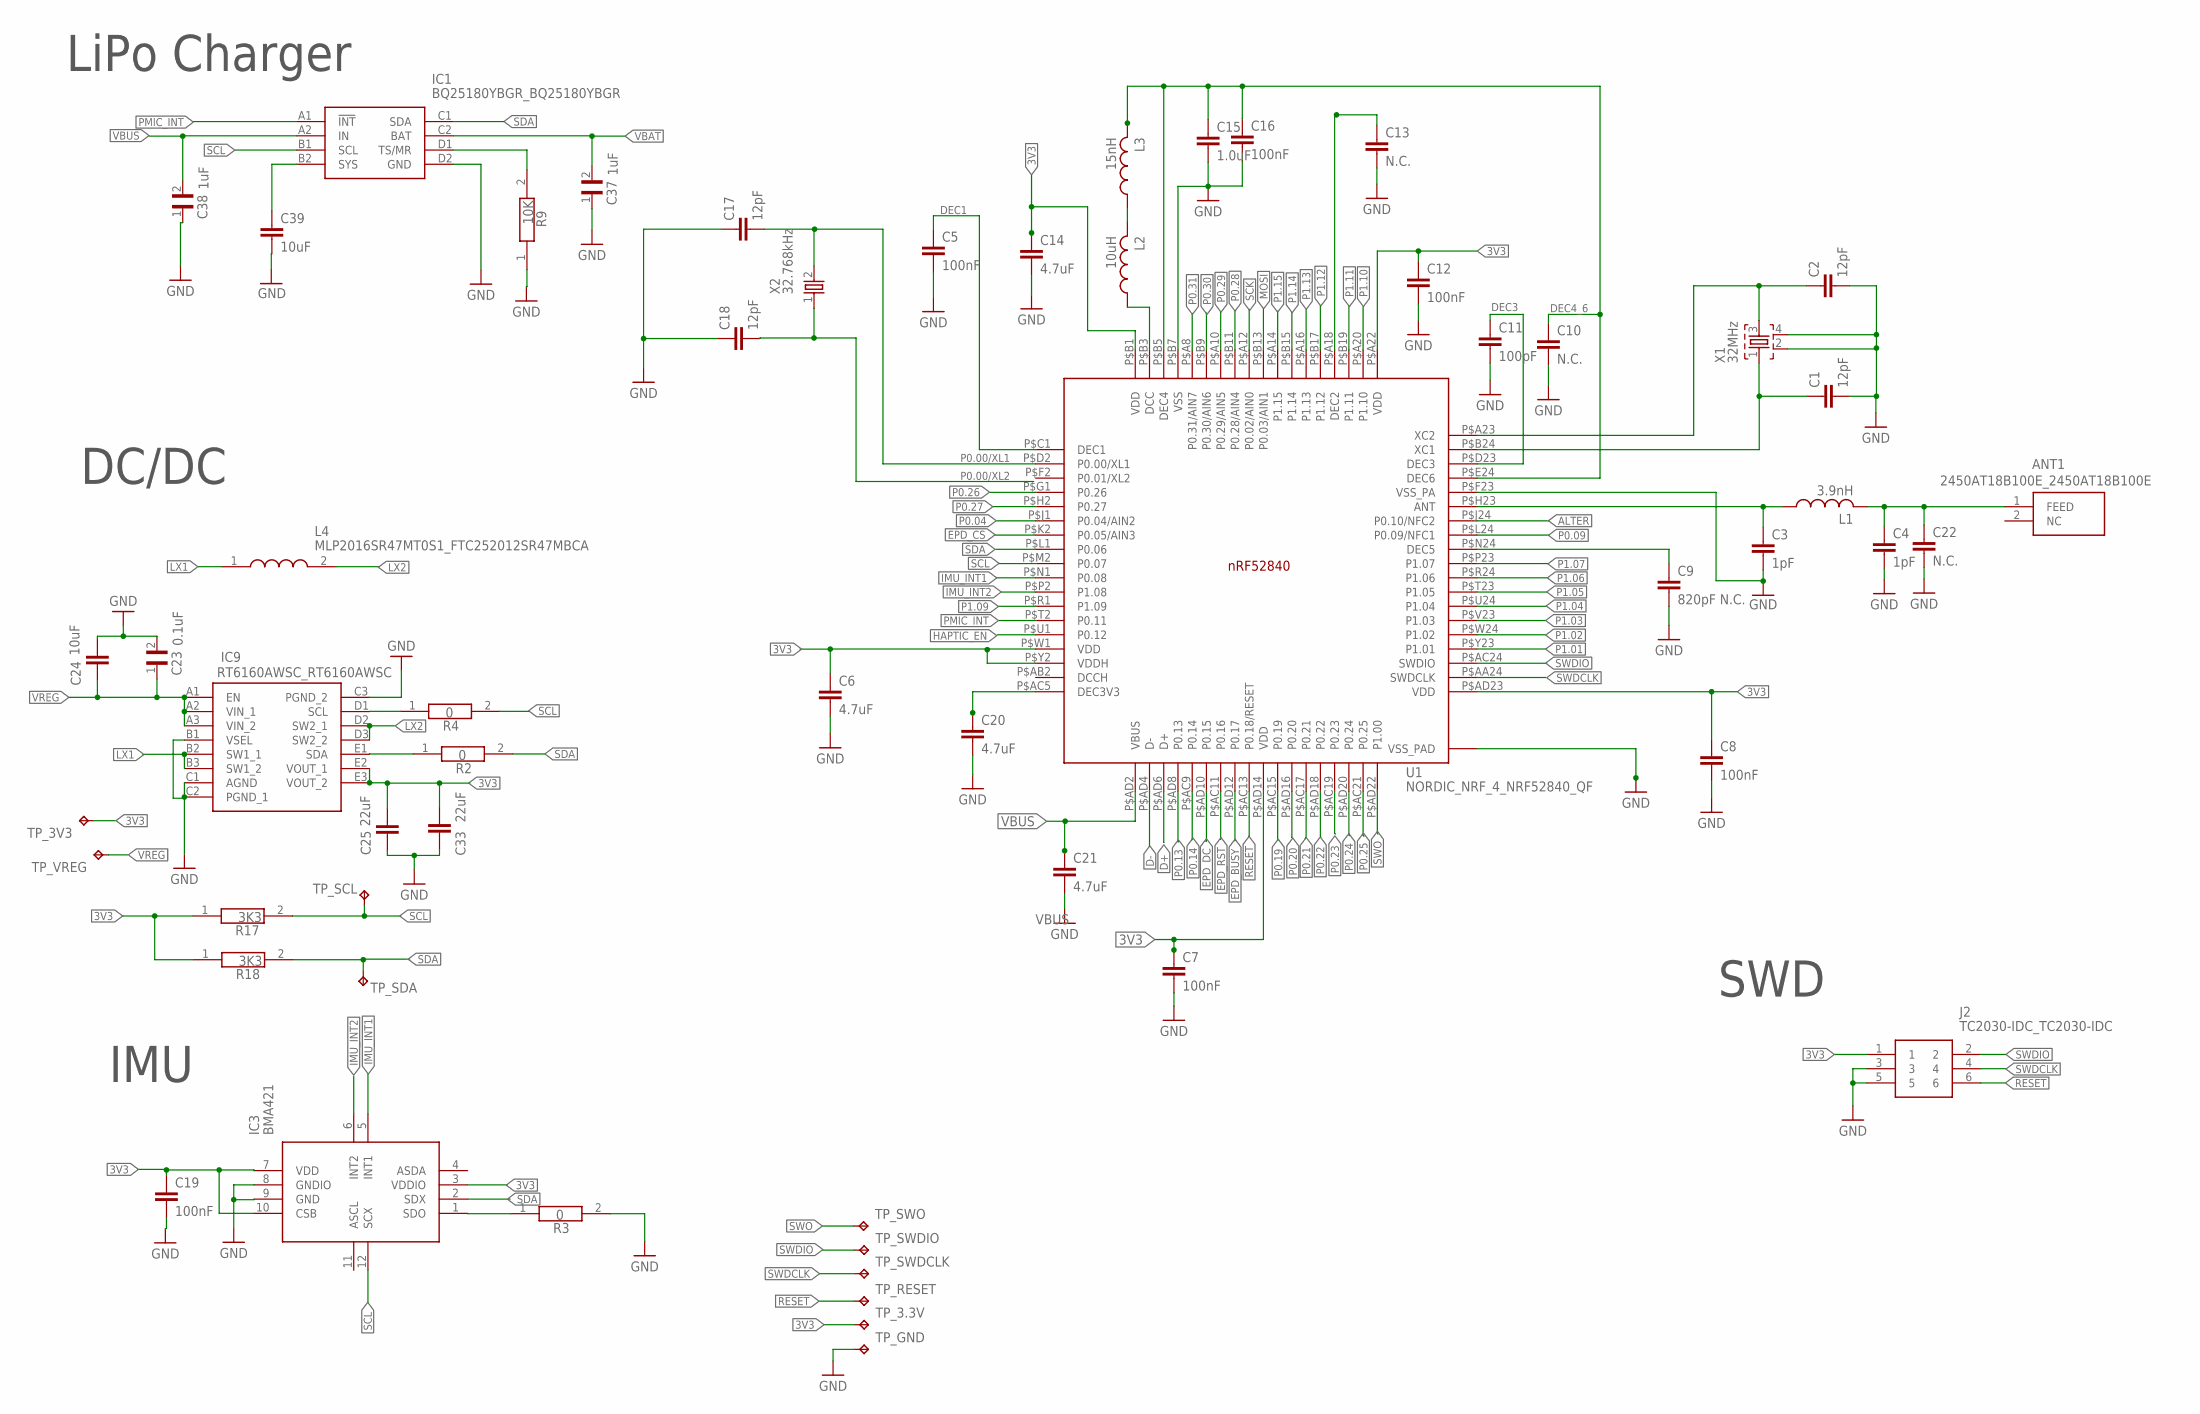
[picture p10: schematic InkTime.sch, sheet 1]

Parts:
ANT1: 2450AT18B100E_2450AT18B100E; 2450AT18B100E_ANTC3216X140N
C1, C2, C17, C18: 12pF; NORDIC_NRF_3_RESC0201_N
C3, C4: 1pF; NORDIC_NRF_3_RESC0201_N
C5, C7, C8, C12, C16, C19: 100nF; NORDIC_NRF_3_RESC0201_N
C6, C14, C20, C21: 4.7uF; NORDIC_NRF_3_RESC0402_N
C9: 820pF N.C.; NORDIC_NRF_3_RESC0201_N
C10: N.C.; NORDIC_NRF_3_RESC0402_N
C11: 100pF; NORDIC_NRF_3_RESC0201_N
C13, C22: N.C.; NORDIC_NRF_3_RESC0201_N
C15: 1.0uF; NORDIC_NRF_3_RESC0402_N
C23: 0.1uF; GRM011R60J152KE01L_2_CAPC0201X13N
C24, C39: 10uF; NORDIC_NRF_3_RESC0402_N
C25, C33: 22uF; NORDIC_NRF_3_RESC0402_N
C37, C38: 1uF; GRM011R60J152KE01L_2_CAPC0201X13N
IC1: BQ25180YBGR_BQ25180YBGR; BQ25180YBGR_BGA8C40P2X4_100X155X50
IC3: BMA421; BMA423_BMA423
IC9: RT6160AWSC_RT6160AWSC; RT6160AWSC_BGA15C40P3X5_140X230X60
J2: TC2030-IDC_TC2030-IDC; TC2030-IDC_TC2030IDC
L1: 3.9nH; NORDIC_NRF_2_RESC0201_N
L2: 10uH; NORDIC_NRF_2_RESC0402_N
L3: 15nH; NORDIC_NRF_2_RESC0201_N
L4: MLP2016SR47MT0S1_FTC252012SR47MBCA; MLP2016SR47MT0S1_INDC2016X100N
R2, R3, R4: 0; CPF0201D7K68C1_0201
R9: 10K; CPF0201D7K68C1_0201
R17, R18: 3K3; CPF0201D7K68C1_0201
TP_3.3V, TP_3V3: HECTOR_WATCH_1_TPTP20R; HECTOR_WATCH_1_TP20R
TP_GND: HECTOR_WATCH_1_TPTP20R; HECTOR_WATCH_1_TP20R
TP_RESET: HECTOR_WATCH_1_TPTP20R; HECTOR_WATCH_1_TP20R
TP_SCL: HECTOR_WATCH_1_TPTP20R; HECTOR_WATCH_1_TP20R
TP_SDA: HECTOR_WATCH_1_TPTP20R; HECTOR_WATCH_1_TP20R
TP_SWDCLK: HECTOR_WATCH_1_TPTP20R; HECTOR_WATCH_1_TP20R
TP_SWDIO: HECTOR_WATCH_1_TPTP20R; HECTOR_WATCH_1_TP20R
TP_SWO: HECTOR_WATCH_1_TPTP20R; HECTOR_WATCH_1_TP20R
TP_VREG: HECTOR_WATCH_1_TPTP20R; HECTOR_WATCH_1_TP20R
U1: NORDIC_NRF_4_NRF52840_QF; NORDIC_NRF_4_AQFN50P700X700X85_HS-74N
X1: 32MHz; NORDIC_NRF_BT-XTAL_2016_N
X2: 32.768kHz; NORDIC_NRF_1_XTAL_3215_N

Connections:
3V3: C6.1, C7.1, C8.1, C12.1, C14.1, C19.1, C25.1, C33.1, IC3.3 (VDDIO), IC3.7 (VDD), IC3.10 (CSB), IC9.E2 (VOUT_1), IC9.E3 (VOUT_2), J2.1, R17.1, R18.1, TP_3.3V.TP, TP_3V3.TP, U1.P$A22 (VDD), U1.P$AD14 (VDD), U1.P$AD23 (VDD), U1.P$B1 (VDD), U1.P$W1 (VDD); also elsewhere on the board
ALTER: U1.P$J24 (P0.10/NFC2); also elsewhere on the board
D+: U1.P$AD6 (D+); also elsewhere on the board
D-: U1.P$AD4 (D-); also elsewhere on the board
DEC1: C5.1, U1.P$C1 (DEC1)
DEC2: C13.1, U1.P$A18 (DEC2)
DEC3: C11.1, U1.P$D23 (DEC3)
DEC4_6: C10.1, C15.1, C16.1, L3.2, U1.P$B5 (DEC4), U1.P$E24 (DEC6)
EPD_BUSY: U1.P$AD12 (P0.17); also elsewhere on the board
EPD_CS: U1.P$K2 (P0.05/AIN3); also elsewhere on the board
EPD_DC: U1.P$AD10 (P0.15); also elsewhere on the board
EPD_RST: U1.P$AC11 (P0.16); also elsewhere on the board
GND: C1.2, C2.2, C3.2, C4.2, C5.2, C6.2, C7.2, C8.2, C9.2, C10.2, C11.2, C12.2, C13.2, C14.2, C15.2, C16.2, C17.1, C18.1, C19.2, C20.2, C21.2, C22.2, C23.2, C24.1, C25.2, C33.2, C37.1, C38.1, C39.2, IC1.D2 (GND), IC3.8 (GNDIO), IC3.9 (GND), IC9.B1 (VSEL), IC9.C1 (AGND), IC9.C2 (PGND_1), IC9.C3 (PGND_2), J2.3, J2.5, R3.2, R9.1, TP_GND.TP, U1.P$74 (VSS_PAD), U1.P$75 (VSS_PAD), U1.P$76 (VSS_PAD), U1.P$77 (VSS_PAD), U1.P$78 (VSS_PAD), U1.P$79 (VSS_PAD), U1.P$80 (VSS_PAD), U1.P$81 (VSS_PAD), U1.P$82 (VSS_PAD), U1.P$83 (VSS_PAD), U1.P$84 (VSS_PAD), U1.P$85 (VSS_PAD), U1.P$86 (VSS_PAD), U1.P$87 (VSS_PAD), U1.P$88 (VSS_PAD), U1.P$89 (VSS_PAD), U1.P$90 (VSS_PAD), U1.P$B7 (VSS), U1.P$F23 (VSS_PA), X1.2, X1.4; also elsewhere on the board
HAPTIC_EN: U1.P$U1 (P0.12); also elsewhere on the board
IMU_INT1: IC3.5 (INT1), U1.P$N1 (P0.08)
IMU_INT2: IC3.6 (INT2), U1.P$P2 (P1.08)
LX1: IC9.B2 (SW1_1), IC9.B3 (SW1_2), L4.1
LX2: IC9.D2 (SW2_1), IC9.D3 (SW2_2), L4.2
MOSI: U1.P$B13 (P0.03/AIN1); also elsewhere on the board
unnamed: L2.2, L3.1
unnamed: C20.1, U1.P$AC5 (DEC3V3)
unnamed: L2.1, U1.P$B3 (DCC)
unnamed: C3.1, L1.1, U1.P$H23 (ANT)
unnamed: C9.1, U1.P$N24 (DEC5)
unnamed: C2.1, U1.P$A23 (XC2), X1.3
unnamed: ANT1.1 (FEED), C4.1, C22.1, L1.2
unnamed: C1.1, U1.P$B24 (XC1), X1.1
unnamed: IC9.D1 (SCL), R4.1
unnamed: IC9.E1 (SDA), R2.1
unnamed: C39.1, IC1.B2 (SYS)
unnamed: IC1.D1 (TS/MR), R9.2
unnamed: IC3.1 (SDO), R3.1
P0.00/XL1: C17.2, U1.P$D2 (P0.00/XL1), X2.2
P0.00/XL2: C18.2, X2.1
P0.04: U1.P$J1 (P0.04/AIN2)
P0.09: U1.P$L24 (P0.09/NFC1)
P0.13: U1.P$AD8 (P0.13); also elsewhere on the board
P0.14: U1.P$AC9 (P0.14); also elsewhere on the board
P0.19: U1.P$AC15 (P0.19)
P0.20: U1.P$AD16 (P0.20)
P0.21: U1.P$AC17 (P0.21)
P0.22: U1.P$AD18 (P0.22)
P0.23: U1.P$AC19 (P0.23)
P0.24: U1.P$AD20 (P0.24)
P0.25: U1.P$AC21 (P0.25)
P0.26: U1.P$G1 (P0.26)
P0.27: U1.P$H2 (P0.27)
P0.28: U1.P$B11 (P0.28/AIN4)
P0.29: U1.P$A10 (P0.29/AIN5)
P0.30: U1.P$B9 (P0.30/AIN6)
P0.31: U1.P$A8 (P0.31/AIN7)
P1.01: U1.P$Y23 (P1.01); also elsewhere on the board
P1.02: U1.P$W24 (P1.02); also elsewhere on the board
P1.03: U1.P$V23 (P1.03)
P1.04: U1.P$U24 (P1.04)
P1.05: U1.P$T23 (P1.05)
P1.06: U1.P$R24 (P1.06)
P1.07: U1.P$P23 (P1.07)
P1.09: U1.P$R1 (P1.09)
P1.10: U1.P$A20 (P1.10)
P1.11: U1.P$B19 (P1.11)
P1.12: U1.P$B17 (P1.12)
P1.13: U1.P$A16 (P1.13)
P1.14: U1.P$B15 (P1.14)
P1.15: U1.P$A14 (P1.15)
PMIC_INT: IC1.A1 (!INT), U1.P$T2 (P0.11)
RESET: J2.6, TP_RESET.TP, U1.P$AC13 (P0.18/RESET); also elsewhere on the board
SCK: U1.P$A12 (P0.02/AIN0); also elsewhere on the board
SCL: IC1.B1 (SCL), IC3.12 (SCX), R4.2, R17.2, TP_SCL.TP, U1.P$M2 (P0.07); also elsewhere on the board
SDA: IC1.C1 (SDA), IC3.2 (SDX), R2.2, R18.2, TP_SDA.TP, U1.P$L1 (P0.06); also elsewhere on the board
SWDCLK: J2.4, TP_SWDCLK.TP, U1.P$AA24 (SWDCLK)
SWDIO: J2.2, TP_SWDIO.TP, U1.P$AC24 (SWDIO)
SWO: TP_SWO.TP, U1.P$AD22 (P1.00)
VBAT: C37.2, IC1.C2 (BAT); also elsewhere on the board
VBUS: C21.1, C38.2, IC1.A2 (IN), U1.P$AD2 (VBUS); also elsewhere on the board
VREG: C23.1, C24.2, IC9.A1 (EN), IC9.A2 (VIN_1), IC9.A3 (VIN_2), TP_VREG.TP

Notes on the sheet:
SWD
IMU
DC/DC
LiPo Charger

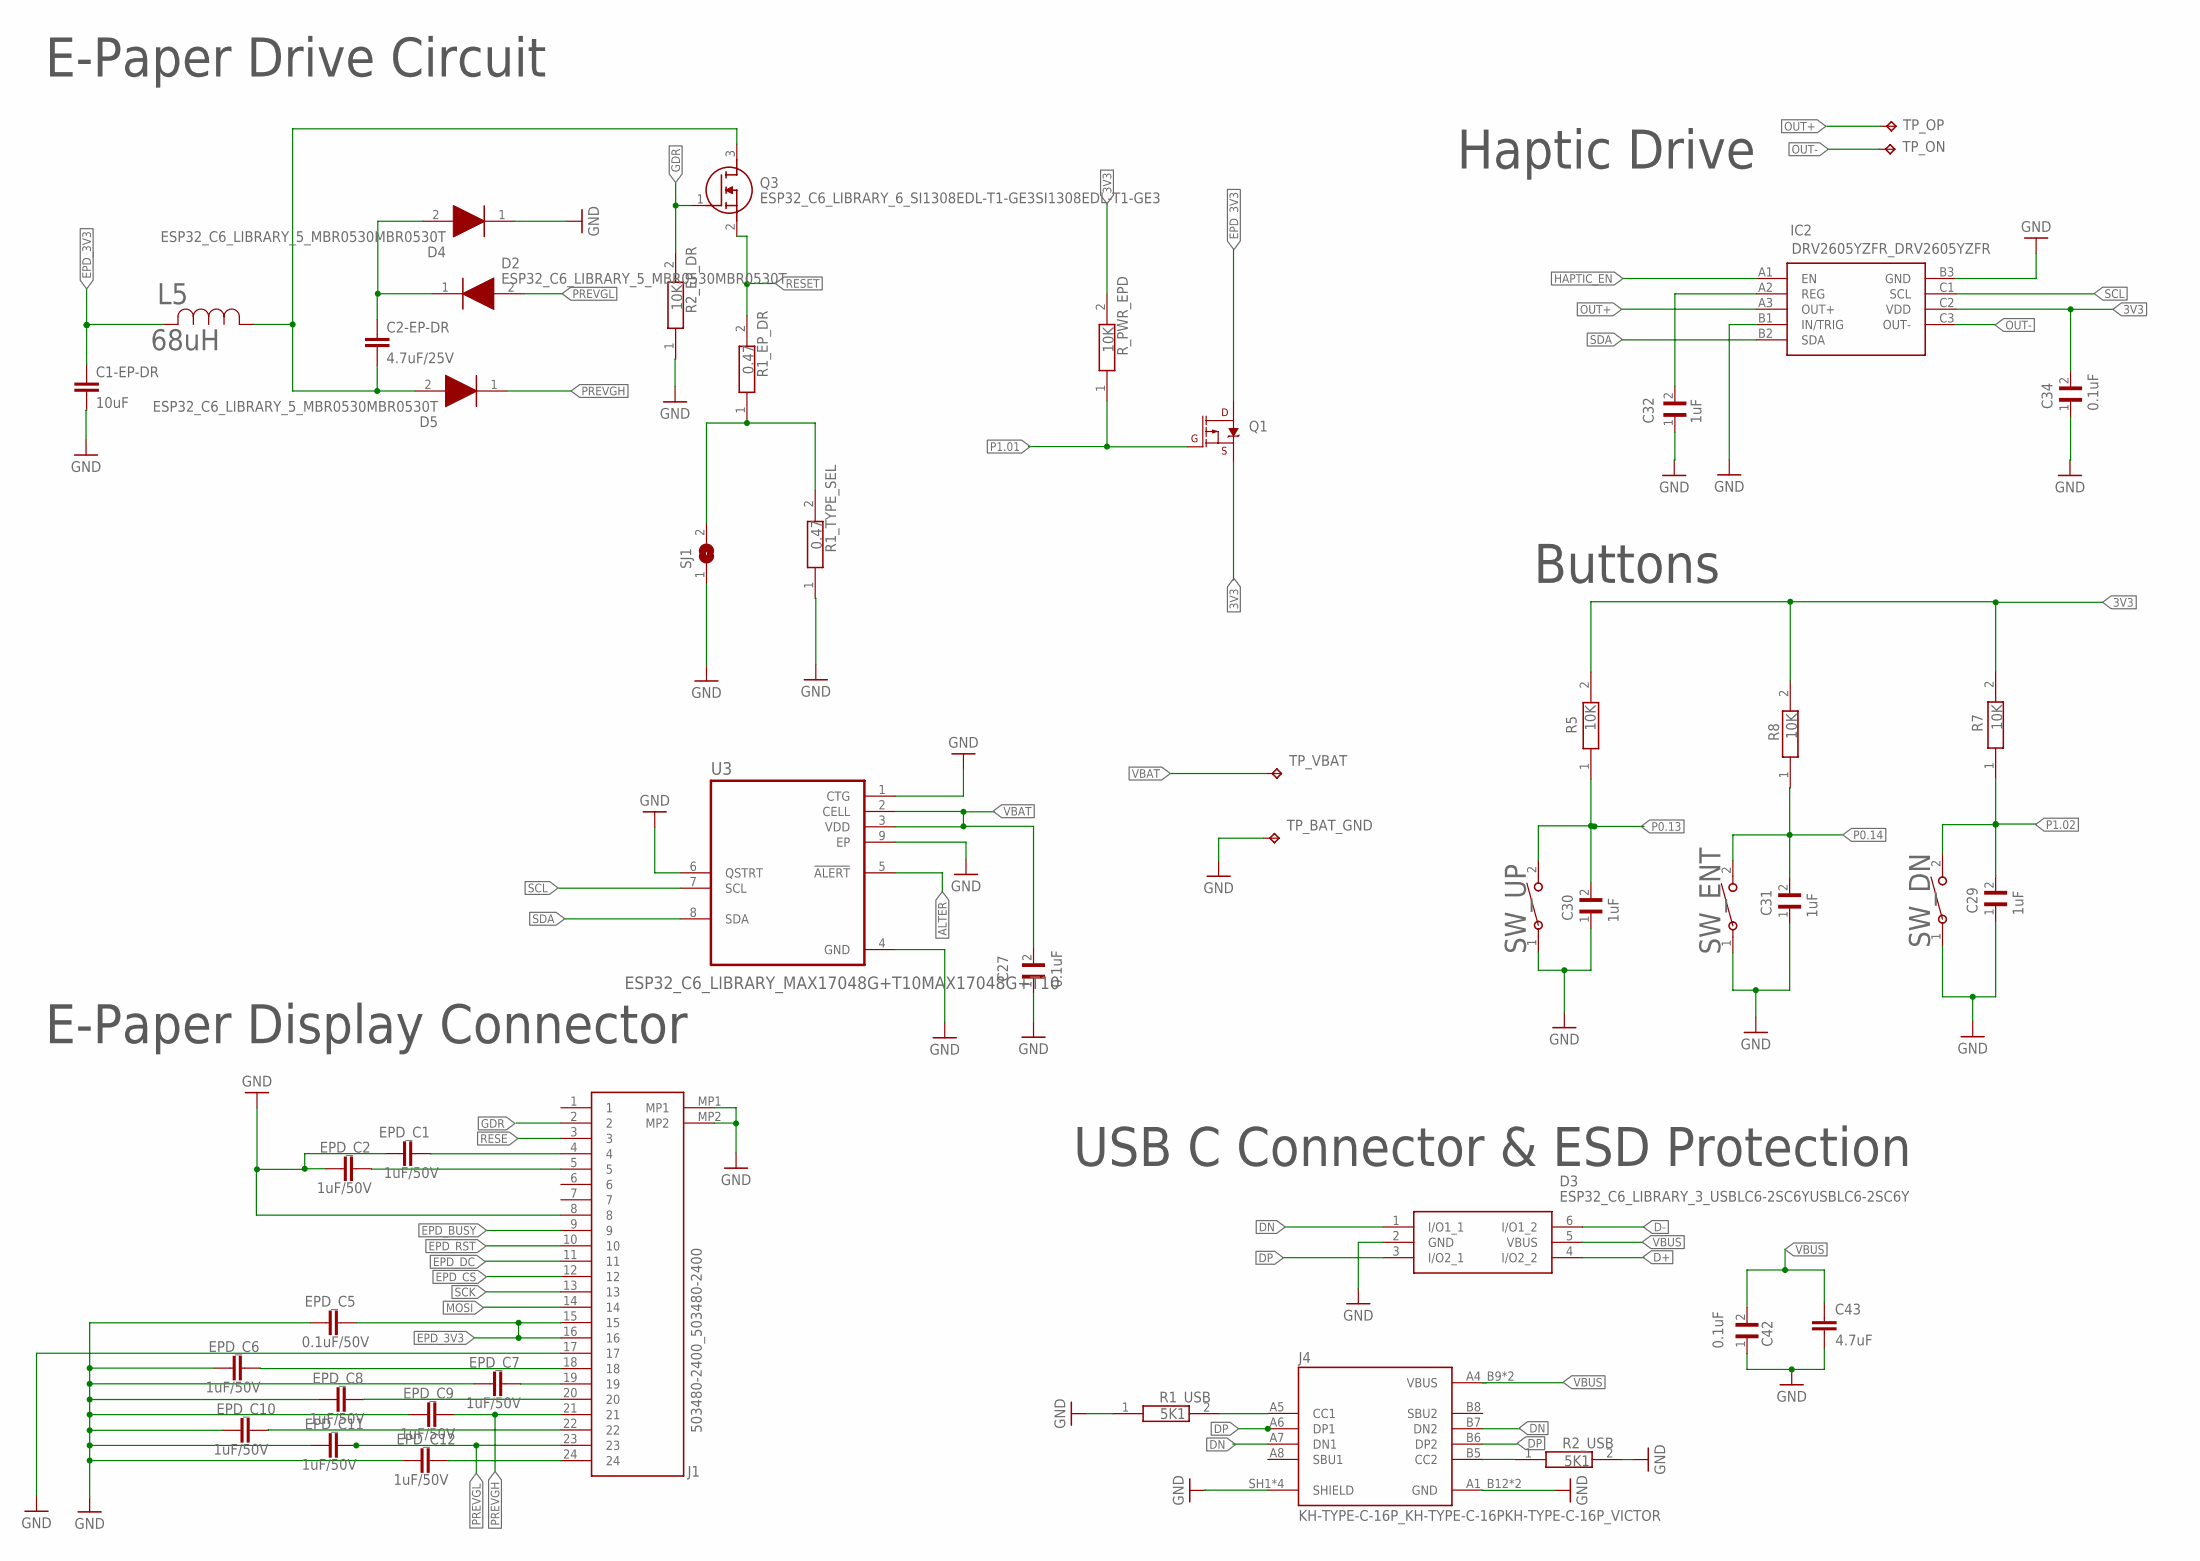
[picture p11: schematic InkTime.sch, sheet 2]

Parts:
C1-EP-DR: 10uF; NORDIC_NRF_3_RESC0402_N
C2-EP-DR: 4.7uF/25V; NORDIC_NRF_3_RESC0201_N
C27, C34, C42: 0.1uF; GRM011R60J152KE01L_2_CAPC0201X13N
C29, C30, C31, C32: 1uF; GRM011R60J152KE01L_2_CAPC0201X13N
C43: 4.7uF; NORDIC_NRF_3_RESC0402_N
D2, D4, D5: ESP32_C6_LIBRARY_5_MBR0530MBR0530T; ESP32_C6_LIBRARY_5_SOD3716X135N
D3: ESP32_C6_LIBRARY_3_USBLC6-2SC6YUSBLC6-2SC6Y; ESP32_C6_LIBRARY_3_SOT95P280X145-6N
EPD_C1, EPD_C2, EPD_C6, EPD_C7, EPD_C8, EPD_C9, EPD_C10, EPD_C11, EPD_C12: 1uF/50V; NORDIC_NRF_3_RESC0402_N
EPD_C5: 0.1uF/50V; NORDIC_NRF_3_RESC0402_N
IC2: DRV2605YZFR_DRV2605YZFR; DRV2605YZFR_BGA9C50P3X3_144X144X62
J1: 503480-2400_503480-2400; 503480-2400_5034802400
J4: KH-TYPE-C-16P_KH-TYPE-C-16PKH-TYPE-C-16P_VICTOR; KH-TYPE-C-16P_KINGHELM_KH-TYPE-C-16P
L5: 68uH; ESP32_C6_LIBRARY_2_IND_4828-WE-TPC_WRE
Q1: ESP32_C6_LIBRARY_4_ESP32_WROVER_SPARKFUN-DISCRETE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; ESP32_C6_LIBRARY_4_ESP32_C6_LIBRARY_4_ESP32_C6_LIBRARY_4_ES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
Q3: ESP32_C6_LIBRARY_6_SI1308EDL-T1-GE3SI1308EDL-T1-G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; ESP32_C6_LIBRARY_6_SOT65P210X110-3N
R1_EP_DR, R1_TYPE_SEL: 0.47; CPF0201D7K68C1_0201
R1_USB, R2_USB: 5K1; CPF0201D7K68C1_0201
R2_EP_DR, R5, R7, R8: 10K; CPF0201D7K68C1_0201
R_PWR_EPD: 10K; CPF0201D7K68C1_0201
SJ1: ESP32_C6_LIBRARY_7_JUMPER_SJ
SW_DN: 2025-10-22_07-23-44_LIBRARY_EVP-AKE31A; 2025-10-22_07-23-44_LIBRARY_SW_EVP-AKE31A_PAN
SW_ENT: 2025-10-22_07-23-44_LIBRARY_EVP-AKE31A; 2025-10-22_07-23-44_LIBRARY_SW_EVP-AKE31A_PAN
SW_UP: 2025-10-22_07-23-44_LIBRARY_EVP-AKE31A; 2025-10-22_07-23-44_LIBRARY_SW_EVP-AKE31A_PAN
TP_BAT_GND: HECTOR_WATCH_1_TPTP20R; HECTOR_WATCH_1_TP20R
TP_ON: HECTOR_WATCH_1_TPTP20R; HECTOR_WATCH_1_TP20R
TP_OP: HECTOR_WATCH_1_TPTP20R; HECTOR_WATCH_1_TP20R
TP_VBAT: HECTOR_WATCH_1_TPTP20R; HECTOR_WATCH_1_TP20R
U3: ESP32_C6_LIBRARY_MAX17048G+T10MAX17048G+T10; ESP32_C6_LIBRARY_SON50P200X200X80-9N

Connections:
3V3: C34.2, IC2.C2 (VDD), Q1.2 (S), R5.2, R7.2, R8.2, R_PWR_EPD.2; also elsewhere on the board
ALTER: U3.5 (!ALERT); also elsewhere on the board
D+: D3.4 (I/O2_2); also elsewhere on the board
D-: D3.6 (I/O1_2); also elsewhere on the board
DN: D3.1 (I/O1_1), J4.A7 (DN1), J4.B7 (DN2)
DP: D3.3 (I/O2_1), J4.A6 (DP1), J4.B6 (DP2)
EPD_3V3: C1-EP-DR.1, EPD_C5.1, J1.15, J1.16, L5.2, Q1.3 (D)
EPD_BUSY: J1.9; also elsewhere on the board
EPD_CS: J1.12; also elsewhere on the board
EPD_DC: J1.11; also elsewhere on the board
EPD_RST: J1.10; also elsewhere on the board
GDR: J1.2, Q3.1 (G), R2_EP_DR.2
GND: C1-EP-DR.2, C27.1, C29.1, C30.1, C31.1, C32.1, C34.1, C42.1, C43.1, D3.2 (GND), D4.1 (K), EPD_C1.2, EPD_C2.2, EPD_C5.2, EPD_C6.2, EPD_C7.2, EPD_C8.2, EPD_C9.2, EPD_C10.2, EPD_C11.2, EPD_C12.2, IC2.B1 (IN/TRIG), IC2.B3 (GND), J1.8, J1.17, J1.MP1, J1.MP2, J4.A1_B12 (GND), J4.A12_B1 (GND), J4.SH1 (SHIELD), J4.SH2 (SHIELD), J4.SH3 (SHIELD), J4.SH4 (SHIELD), R1_TYPE_SEL.1, R1_USB.1, R2_EP_DR.1, R2_USB.2, SJ1.1, SW_DN.1, SW_ENT.1, SW_UP.1, TP_BAT_GND.TP, U3.1 (CTG), U3.4 (GND), U3.6 (QSTRT), U3.9 (EP); also elsewhere on the board
HAPTIC_EN: IC2.A1 (EN); also elsewhere on the board
MOSI: J1.14; also elsewhere on the board
unnamed: C2-EP-DR.2, D5.2 (A), L5.1, Q3.3 (D)
unnamed: C2-EP-DR.1, D2.1 (K), D4.2 (A)
unnamed: J4.B5 (CC2), R2_USB.1
unnamed: R1_EP_DR.1, R1_TYPE_SEL.2, SJ1.2
unnamed: J4.A5 (CC1), R1_USB.2
unnamed: C32.2, IC2.A2 (REG)
unnamed: EPD_C1.1, J1.4
unnamed: EPD_C2.1, J1.5
unnamed: EPD_C6.1, J1.18
unnamed: EPD_C7.1, J1.19
unnamed: EPD_C8.1, J1.20
unnamed: EPD_C10.1, J1.22
unnamed: EPD_C12.1, J1.24
OUT+: IC2.A3 (OUT+), TP_OP.TP
OUT-: IC2.C3 (OUT-), TP_ON.TP
P0.13: C30.2, R5.1, SW_UP.2; also elsewhere on the board
P0.14: C31.2, R8.1, SW_ENT.2; also elsewhere on the board
P1.01: Q1.1 (G), R_PWR_EPD.1; also elsewhere on the board
P1.02: C29.2, R7.1, SW_DN.2; also elsewhere on the board
PREVGH: D5.1 (K), EPD_C9.1, J1.21
PREVGL: D2.2 (A), EPD_C11.1, J1.23
RESE: J1.3
RESET: Q3.2 (S), R1_EP_DR.2; also elsewhere on the board
SCK: J1.13; also elsewhere on the board
SCL: IC2.C1 (SCL), U3.7 (SCL); also elsewhere on the board
SDA: IC2.B2 (SDA), U3.8 (SDA); also elsewhere on the board
VBAT: C27.2, TP_VBAT.TP, U3.2 (CELL), U3.3 (VDD); also elsewhere on the board
VBUS: C42.2, C43.2, D3.5 (VBUS), J4.A4_B9 (VBUS), J4.A9_B4 (VBUS); also elsewhere on the board

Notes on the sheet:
E-Paper Drive Circuit
Haptic Drive
Buttons
E-Paper Display Connector
USB C Connector & ESD Protection

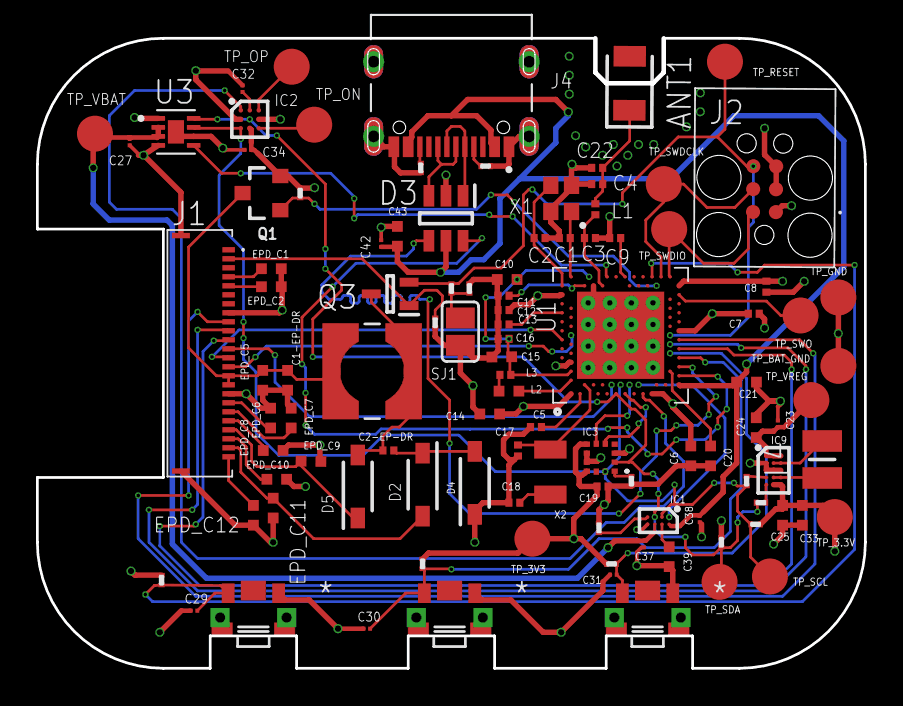
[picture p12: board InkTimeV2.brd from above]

Board: 4 copper layers, 46.0 x 35.0 mm, 105 parts (0 on the bottom side), 70 nets.

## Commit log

2026-04-08 Update README with project details and BOM
2026-04-15 PDF pentru Schematic
2026-04-15 PCB V2
    [InkTimeV2.brd]

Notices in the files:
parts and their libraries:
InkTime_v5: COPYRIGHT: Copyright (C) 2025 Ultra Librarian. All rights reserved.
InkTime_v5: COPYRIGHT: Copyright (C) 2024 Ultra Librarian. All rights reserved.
